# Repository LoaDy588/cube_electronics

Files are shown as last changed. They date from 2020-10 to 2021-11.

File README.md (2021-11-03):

# Cube Electronics

## Content

The repo currently contains KiCAD source files for the main board, interface board and a tiny sensor head.
It also includes all accompanying files, such as BOM.

## Building

The supplied `makefile` uses [KiKit](https://github.com/yaqwsx/KiKit) to automatically generate all output gerber files for JLCPCB.
Just run `make` in the top level directory to create all output gerbers and zip them in the `./gerber/` folder.

## 3D models, schematic symbols, footprints

This project relies on [LoaDy KiCAD Libs](https://github.com/LoaDy588/LoaDy_KiCAD_libs) for some footprints and the 3D models in the 3D preview on PCBNew

## License

The Main Board and Interface Board are licensed under CERN-OHL-W v2.

The MLX90393 sensor head is not licensed at all.

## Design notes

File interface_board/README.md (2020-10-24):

# Interface Board

This board serves as a sensor interface on the moving head.

It includes power regulators, GPIO and two communication busses - I2C and SPI.

It communicates with the main board via buffered 12V I2C bus.

## License

Copyright Oldřich Pecák 2020.

This source describes Open Hardware and is licensed under the CERN-OHL-W v2.

You may redistribute and modify this source and make products using it under the terms of the CERN-OHL-W v2 (https://ohwr.org/cern_ohl_w_v2.txt).

This source is distributed WITHOUT ANY EXPRESS OR IMPLIED WARRANTY, INCLUDING OF MERCHANTABILITY, SATISFACTORY QUALITY AND FITNESS FOR A PARTICULAR PURPOSE. Please see the CERN-OHL-W v2 for applicable conditions.

Source location: LICENSE.txt

As per CERN-OHL-W v2 section 4, should You produce hardware based on this source, You must where practicable maintain the Source Location visible on the external case of the Gizmo or other products you make using this source.

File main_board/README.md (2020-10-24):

# Main Board

This is the main control board for Cube.

## Features
- powered by STM32G4 170MHz Cortex-M4 MCU
- four independent TMC2209 stepper drivers
- fully protected 10x limit switch inputs capable of 12V input
- USB communication with PC
- I2C and UART passthrough to MCU
- 3V3, 5V and 12V(supply) power rails

## License

Copyright Oldřich Pecák 2020.

This source describes Open Hardware and is licensed under the CERN-OHL-W v2.

You may redistribute and modify this source and make products using it under the terms of the CERN-OHL-S v2 (https://ohwr.org/cern_ohl_w_v2.txt).

This source is distributed WITHOUT ANY EXPRESS OR IMPLIED WARRANTY, INCLUDING OF MERCHANTABILITY, SATISFACTORY QUALITY AND FITNESS FOR A PARTICULAR PURPOSE. Please see the CERN-OHL-W v2 for applicable conditions.

Source location: LICENSE.txt

As per CERN-OHL-W v2 section 4, should You produce hardware based on this source, You must where practicable maintain the Source Location visible on the external case of the Gizmo or other products you make using this source.

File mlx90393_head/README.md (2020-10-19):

# MLX90393

This is a tiny carrier board for the MLX90393 sensor.

## BOM

- Melexis MLX90393 sensor, in QFN-16 package
- 2x: 100nF X7R MLCC capacitor, 0603 package (imperial)

## License

No license, as this is extremely simple board.

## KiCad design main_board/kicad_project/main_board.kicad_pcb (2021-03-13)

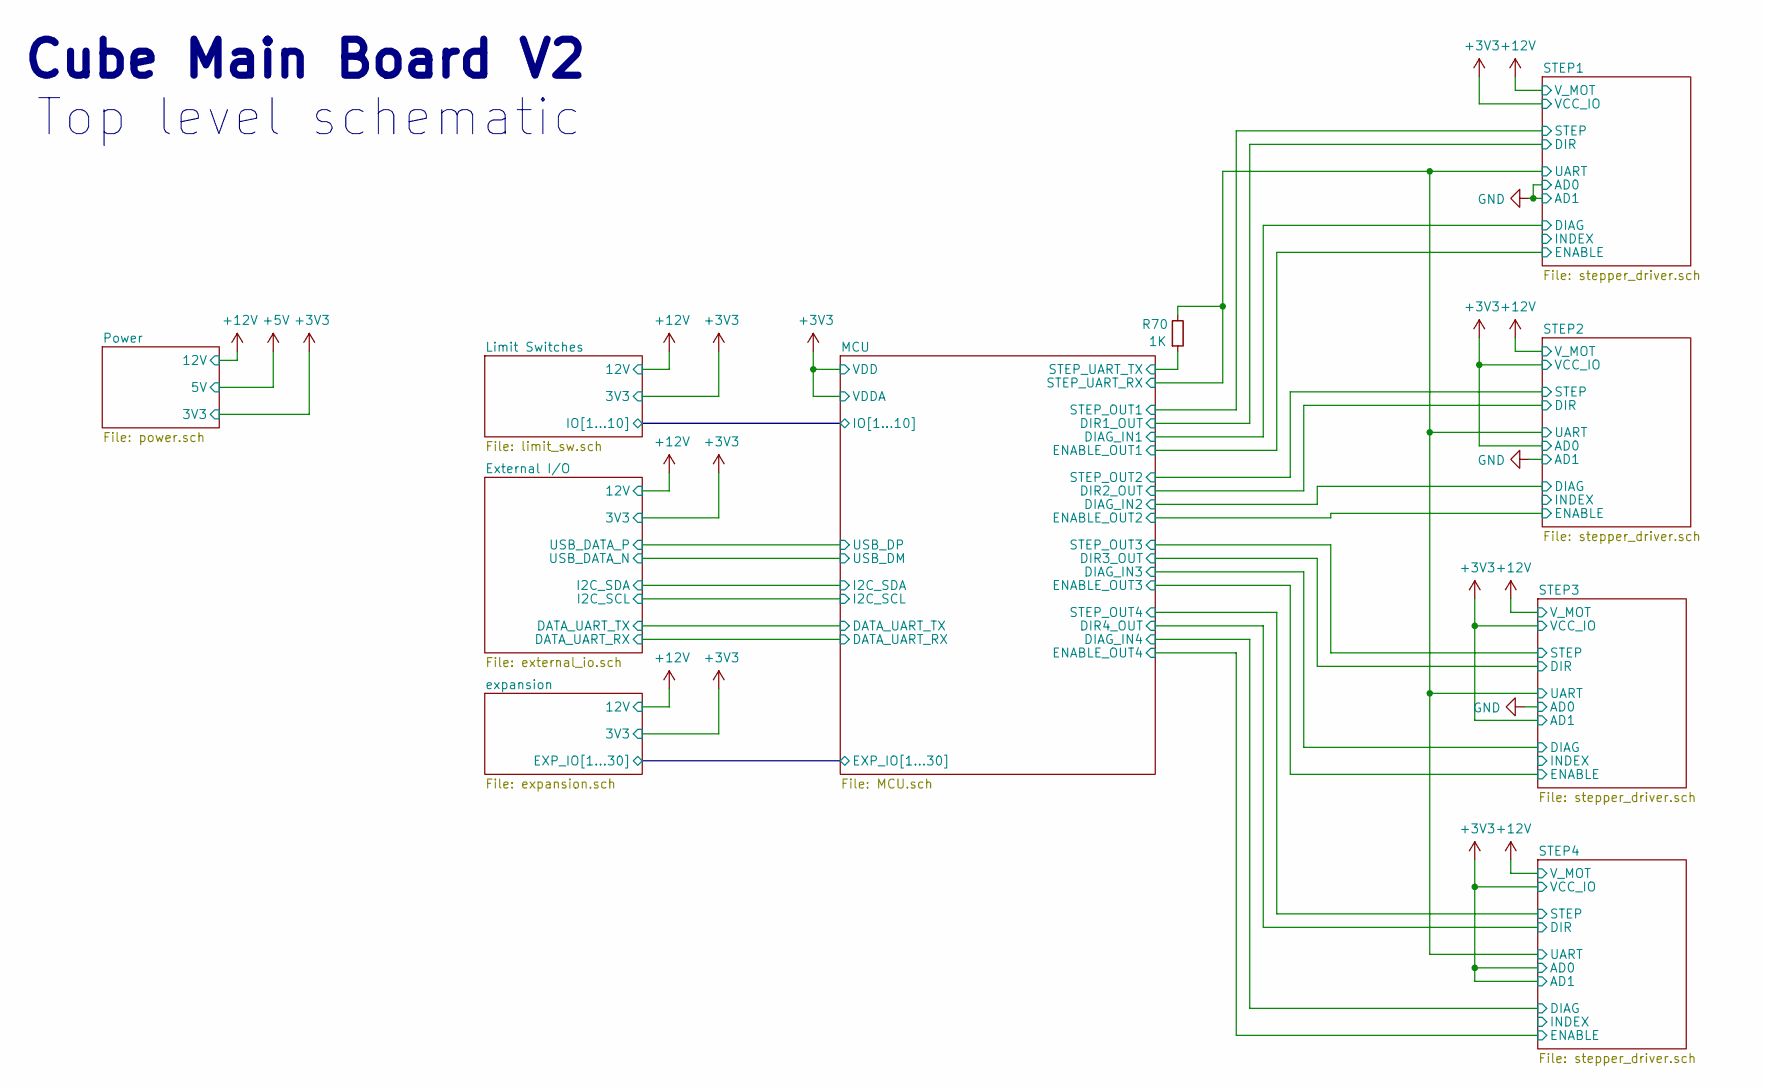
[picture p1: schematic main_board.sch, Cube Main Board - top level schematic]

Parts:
R70: 1K; R_0603_1608Metric

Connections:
/MCU/STEP_UART_RX: R70.2; also elsewhere on the board
/MCU/STEP_UART_TX: R70.1; also elsewhere on the board

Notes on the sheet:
Cube Main Board V2
Top level schematic

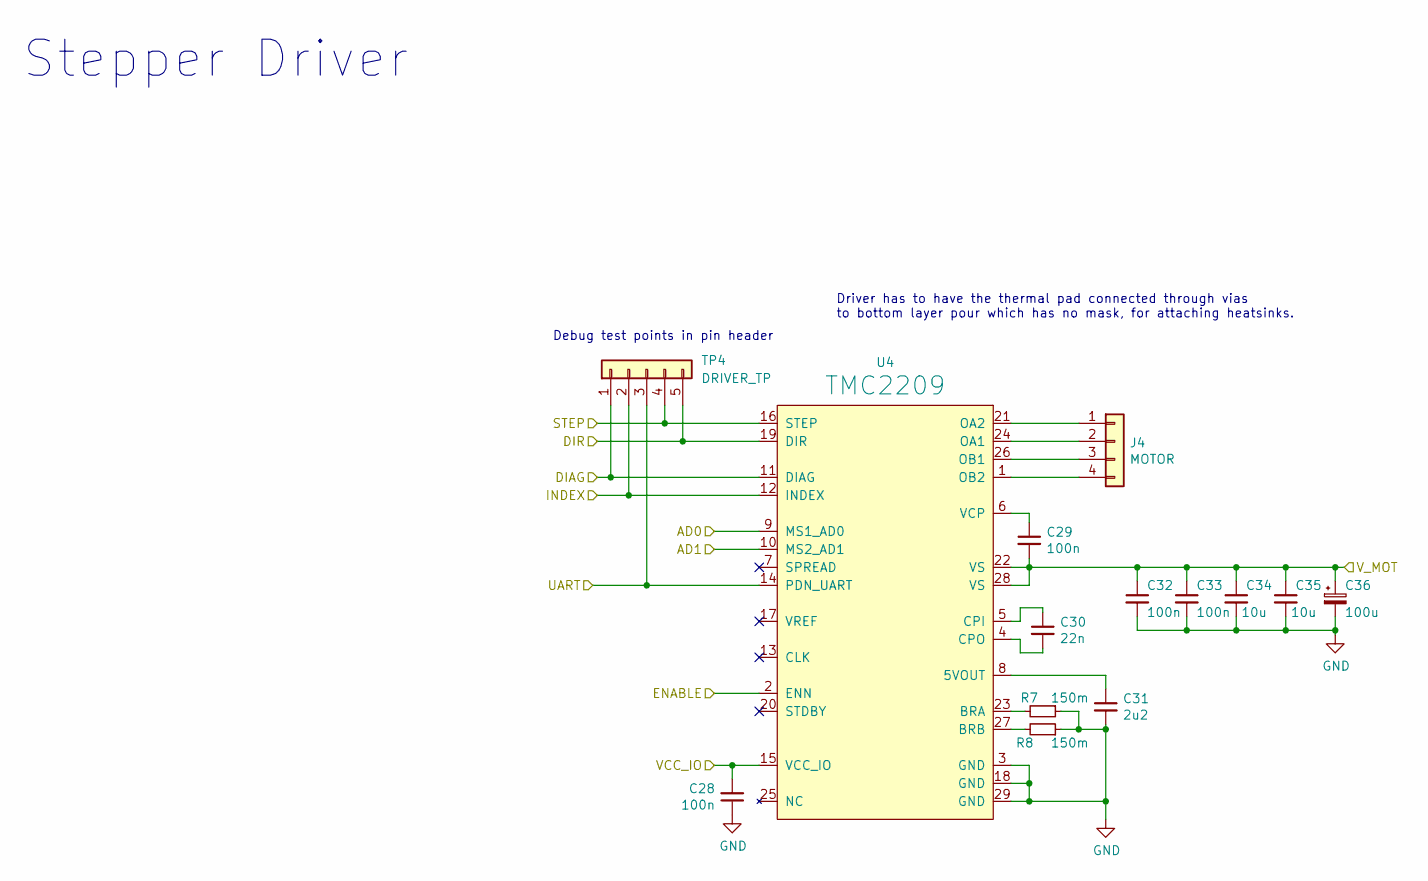
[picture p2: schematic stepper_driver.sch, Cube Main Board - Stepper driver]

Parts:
C1, C2, C5, C6: 100n; C_0603_1608Metric
C3: 22n; C_0603_1608Metric
C4: 2u2; C_0603_1608Metric
C7, C8: 10u; C_1210_3225Metric
C9: 100u; CP_Elec_8x10
J1: MOTOR; Molex_70543-0003
R1, R2: 150m; R_1206_3216Metric
TP1: DRIVER_TP; PinHeader_1x05_P2.54mm_Vertical
U1: TMC2209; TMC2209-LA

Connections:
+3V3: C1.2, U1.15 (VCC_IO); also elsewhere on the board
+12V: C2.2, C5.1, C6.1, C7.1, C8.1, C9.1, U1.22 (VS), U1.28 (VS); also elsewhere on the board
/MCU/STEP_UART_RX: TP1.3, U1.14 (PDN_UART); also elsewhere on the board
/STEP1/DIAG: TP1.1, U1.11 (DIAG); also elsewhere on the board
/STEP1/DIR: TP1.5, U1.19 (DIR); also elsewhere on the board
/STEP1/ENABLE: U1.2 (ENN); also elsewhere on the board
/STEP1/INDEX: TP1.2, U1.12 (INDEX)
/STEP1/STEP: TP1.4, U1.16 (STEP); also elsewhere on the board
GND: C1.1, C4.2, C5.2, C6.2, C7.2, C8.2, C9.2, R1.1, R2.1, U1.3 (GND), U1.9 (MS1_AD0), U1.10 (MS2_AD1), U1.18 (GND), U1.29 (GND); also elsewhere on the board
unnamed: C2.1, U1.6 (VCP)
unnamed: C3.1, U1.5 (CPI)
unnamed: C3.2, U1.4 (CPO)
unnamed: C4.1, U1.8 (5VOUT)
unnamed: J1.1, U1.21 (OA2)
unnamed: J1.2, U1.24 (OA1)
unnamed: J1.3, U1.26 (OB1)
unnamed: J1.4, U1.1 (OB2)
unnamed: R1.2, U1.23 (BRA)
unnamed: R2.2, U1.27 (BRB)

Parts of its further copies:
C10, C11, C14, C15, C19, C20, C23, C24, C28, C29, C32, C33: 100n; C_0603_1608Metric
C12, C21, C30: 22n; C_0603_1608Metric
C13, C22, C31: 2u2; C_0603_1608Metric
C16, C17, C25, C26, C34, C35: 10u; C_1210_3225Metric
C18, C27, C36: 100u; CP_Elec_8x10
J2, J3, J4: MOTOR; Molex_70543-0003
R3, R4, R5, R6, R7, R8: 150m; R_1206_3216Metric
TP2, TP3, TP4: DRIVER_TP; PinHeader_1x05_P2.54mm_Vertical
U2, U3, U4: TMC2209; TMC2209-LA

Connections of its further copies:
+3V3: C10.2, C19.2, C28.2, U2.9 (MS1_AD0), U2.15 (VCC_IO), U3.10 (MS2_AD1), U3.15 (VCC_IO), U4.9 (MS1_AD0), U4.10 (MS2_AD1), U4.15 (VCC_IO); also elsewhere on the board
+12V: C11.2, C14.1, C15.1, C16.1, C17.1, C18.1, C20.2, C23.1, C24.1, C25.1, C26.1, C27.1, C29.2, C32.1, C33.1, C34.1, C35.1, C36.1, U2.22 (VS), U2.28 (VS), U3.22 (VS), U3.28 (VS), U4.22 (VS), U4.28 (VS); also elsewhere on the board
/MCU/STEP_UART_RX: TP2.3, TP3.3, TP4.3, U2.14 (PDN_UART), U3.14 (PDN_UART), U4.14 (PDN_UART); also elsewhere on the board
/STEP2/DIAG: TP2.1, U2.11 (DIAG); also elsewhere on the board
/STEP2/DIR: TP2.5, U2.19 (DIR); also elsewhere on the board
/STEP2/ENABLE: U2.2 (ENN); also elsewhere on the board
/STEP2/INDEX: TP2.2, U2.12 (INDEX)
/STEP2/STEP: TP2.4, U2.16 (STEP); also elsewhere on the board
/STEP3/DIAG: TP3.1, U3.11 (DIAG); also elsewhere on the board
/STEP3/DIR: TP3.5, U3.19 (DIR); also elsewhere on the board
/STEP3/ENABLE: U3.2 (ENN); also elsewhere on the board
/STEP3/INDEX: TP3.2, U3.12 (INDEX)
/STEP3/STEP: TP3.4, U3.16 (STEP); also elsewhere on the board
/STEP4/DIAG: TP4.1, U4.11 (DIAG); also elsewhere on the board
/STEP4/DIR: TP4.5, U4.19 (DIR); also elsewhere on the board
/STEP4/ENABLE: U4.2 (ENN); also elsewhere on the board
/STEP4/INDEX: TP4.2, U4.12 (INDEX)
/STEP4/STEP: TP4.4, U4.16 (STEP); also elsewhere on the board
GND: C10.1, C13.2, C14.2, C15.2, C16.2, C17.2, C18.2, C19.1, C22.2, C23.2, C24.2, C25.2, C26.2, C27.2, C28.1, C31.2, C32.2, C33.2, C34.2, C35.2, C36.2, R3.1, R4.1, R5.1, R6.1, R7.1, R8.1, U2.3 (GND), U2.10 (MS2_AD1), U2.18 (GND), U2.29 (GND), U3.3 (GND), U3.9 (MS1_AD0), U3.18 (GND), U3.29 (GND), U4.3 (GND), U4.18 (GND), U4.29 (GND); also elsewhere on the board
unnamed: C11.1, U2.6 (VCP)
unnamed: C12.1, U2.5 (CPI)
unnamed: C12.2, U2.4 (CPO)
unnamed: C13.1, U2.8 (5VOUT)
unnamed: C20.1, U3.6 (VCP)
unnamed: C21.1, U3.5 (CPI)
unnamed: C21.2, U3.4 (CPO)
unnamed: C22.1, U3.8 (5VOUT)
unnamed: C29.1, U4.6 (VCP)
unnamed: C30.1, U4.5 (CPI)
unnamed: C30.2, U4.4 (CPO)
unnamed: C31.1, U4.8 (5VOUT)
unnamed: J2.1, U2.21 (OA2)
unnamed: J2.2, U2.24 (OA1)
unnamed: J2.3, U2.26 (OB1)
unnamed: J2.4, U2.1 (OB2)
unnamed: J3.1, U3.21 (OA2)
unnamed: J3.2, U3.24 (OA1)
unnamed: J3.3, U3.26 (OB1)
unnamed: J3.4, U3.1 (OB2)
unnamed: J4.1, U4.21 (OA2)
unnamed: J4.2, U4.24 (OA1)
unnamed: J4.3, U4.26 (OB1)
unnamed: J4.4, U4.1 (OB2)
unnamed: R3.2, U2.23 (BRA)
unnamed: R4.2, U2.27 (BRB)
unnamed: R5.2, U3.23 (BRA)
unnamed: R6.2, U3.27 (BRB)
unnamed: R7.2, U4.23 (BRA)
unnamed: R8.2, U4.27 (BRB)

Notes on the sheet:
Stepper Driver
Debug test points in pin header
Driver has to have the thermal pad connected through vias to bottom layer pour which has no mask, for attaching heatsinks.

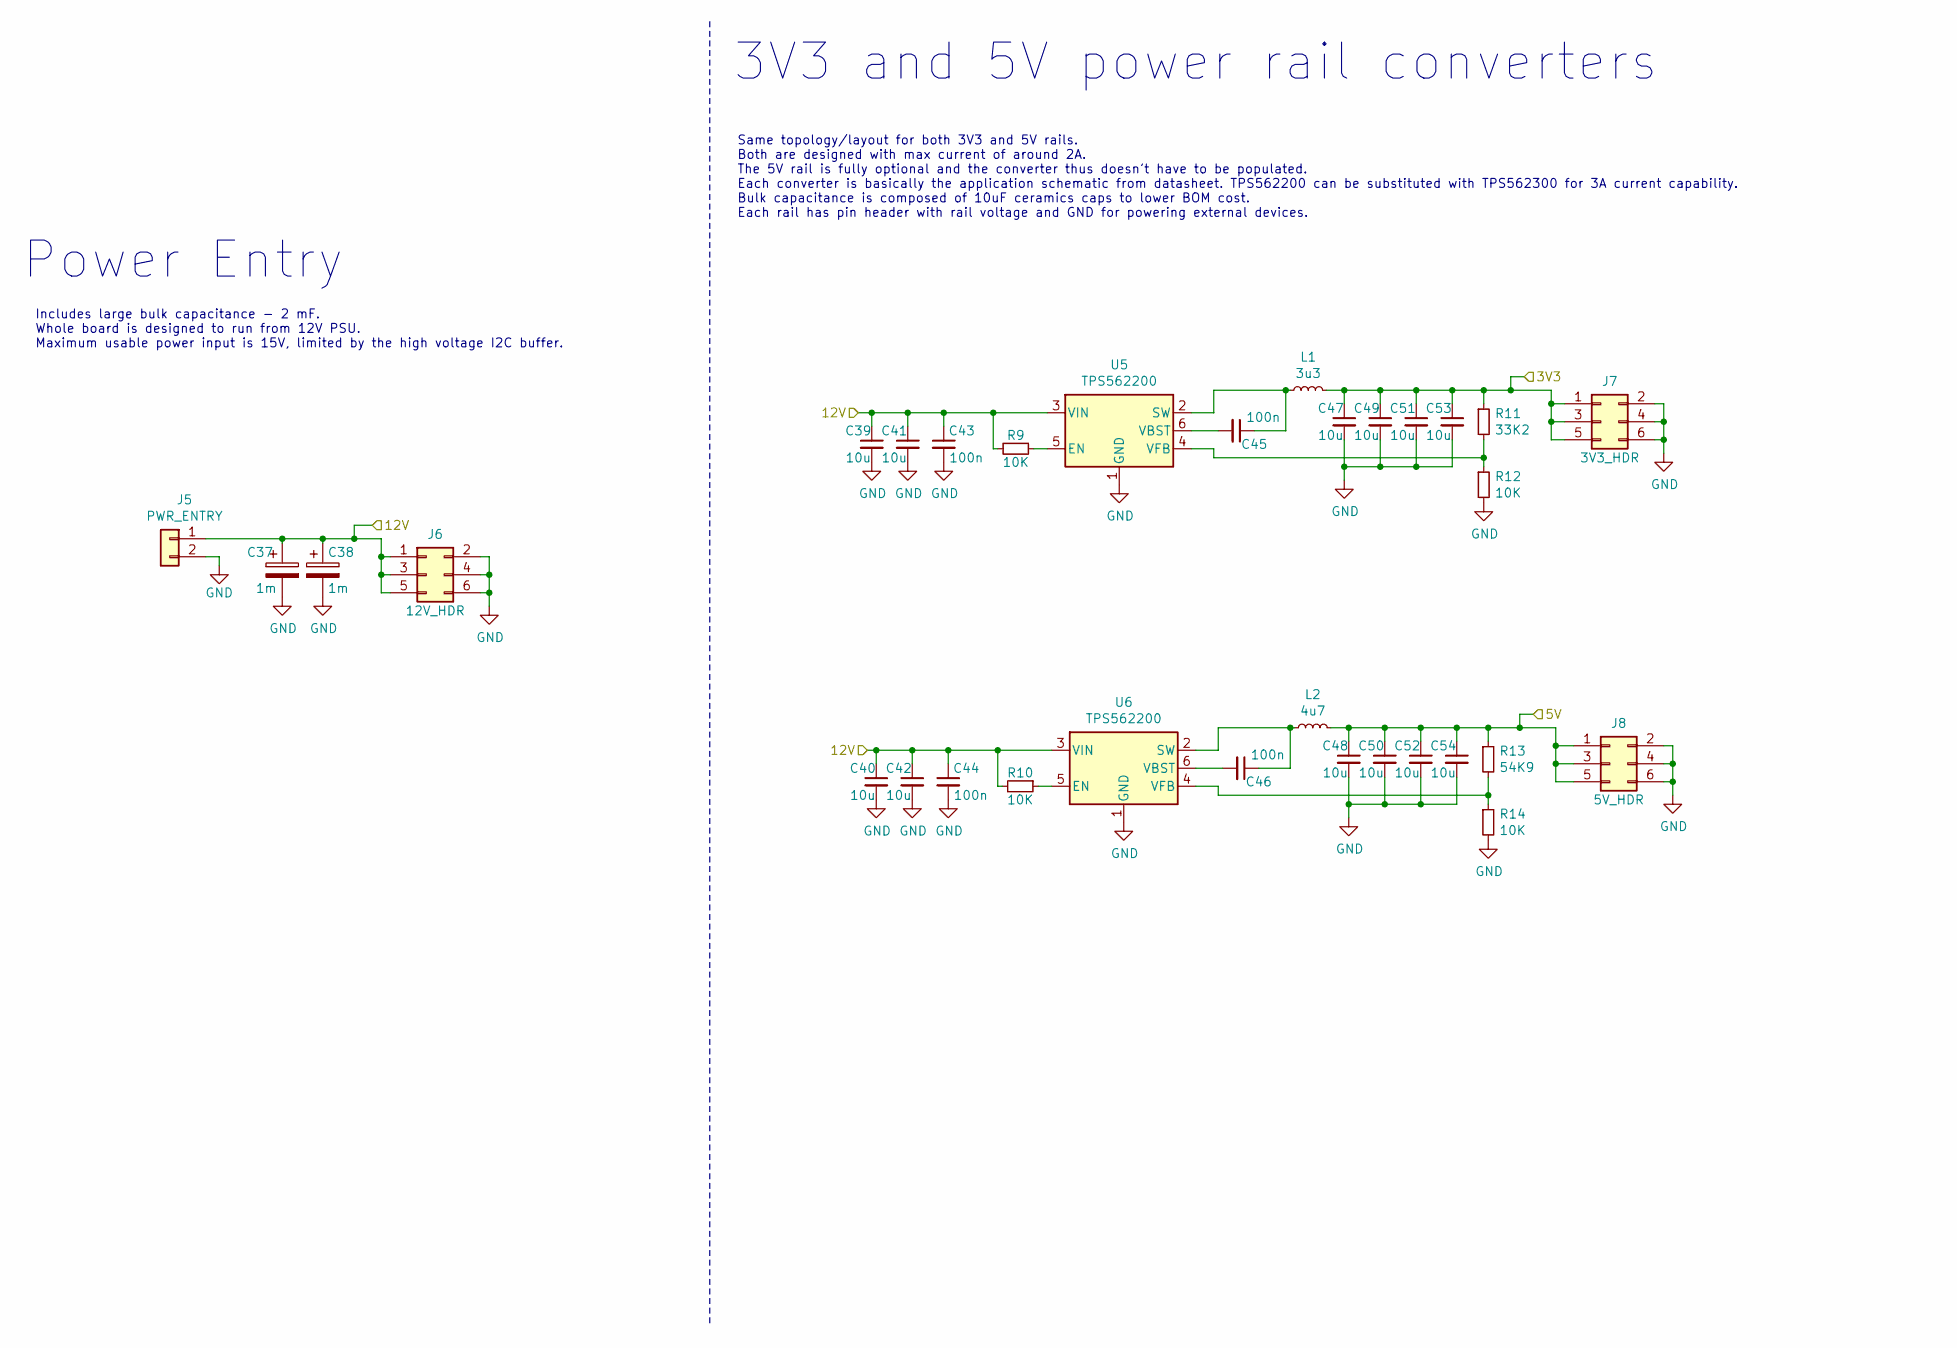
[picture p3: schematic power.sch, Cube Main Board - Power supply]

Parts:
C37, C38: 1m; CP_Radial_D12.5mm_P5.00mm
C39, C40, C41, C42, C47, C48, C49, C50, C51, C52, C53, C54: 10u; C_1210_3225Metric
C43, C44, C45, C46: 100n; C_0603_1608Metric
J5: PWR_ENTRY; PhoenixContact_MSTBA_2,5_2-G-5,08_1x02_P5.08mm_Horizontal
J6: 12V_HDR; PinHeader_2x03_P2.54mm_Vertical
J7: 3V3_HDR; PinHeader_2x03_P2.54mm_Vertical
J8: 5V_HDR; PinHeader_2x03_P2.54mm_Vertical
L1: 3u3; BOURNS_SRP3020TA
L2: 4u7; BOURNS_SRP3020TA
R9, R10, R12, R14: 10K; R_0603_1608Metric
R11: 33K2; R_0603_1608Metric
R13: 54K9; R_0603_1608Metric
U5, U6: TPS562200; SOT-23-6

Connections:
+3V3: C47.1, C49.1, C51.1, C53.1, J7.1, J7.3, J7.5, L1.2, R11.1; also elsewhere on the board
+5V: C48.1, C50.1, C52.1, C54.1, J8.1, J8.3, J8.5, L2.2, R13.1
+12V: C37.1, C38.1, C39.1, C40.1, C41.1, C42.1, C43.1, C44.1, J5.1, J6.1, J6.3, J6.5, R9.2, R10.2, U5.3 (VIN), U6.3 (VIN); also elsewhere on the board
GND: C37.2, C38.2, C39.2, C40.2, C41.2, C42.2, C43.2, C44.2, C47.2, C48.2, C49.2, C50.2, C51.2, C52.2, C53.2, C54.2, J5.2, J6.2, J6.4, J6.6, J7.2, J7.4, J7.6, J8.2, J8.4, J8.6, R12.2, R14.2, U5.1 (GND), U6.1 (GND); also elsewhere on the board
unnamed: C45.1, L1.1, U5.2 (SW)
unnamed: C45.2, U5.6 (VBST)
unnamed: C46.1, L2.1, U6.2 (SW)
unnamed: C46.2, U6.6 (VBST)
unnamed: R9.1, U5.5 (EN)
unnamed: R10.1, U6.5 (EN)
unnamed: R11.2, R12.1, U5.4 (VFB)
unnamed: R13.2, R14.1, U6.4 (VFB)

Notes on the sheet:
Power Entry
3V3 and 5V power rail converters
Includes large bulk capacitance - 2 mF. Whole board is designed to run from 12V PSU. Maximum usable power input is 15V, limited by the high voltage I2C buffer.
Same topology/layout for both 3V3 and 5V rails. Both are designed with max current of around 2A. The 5V rail is fully optional and the converter thus doesn't have to be populated. Each converter is basically the application schematic from datasheet. TPS562200 can be substituted with TPS562300 for 3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

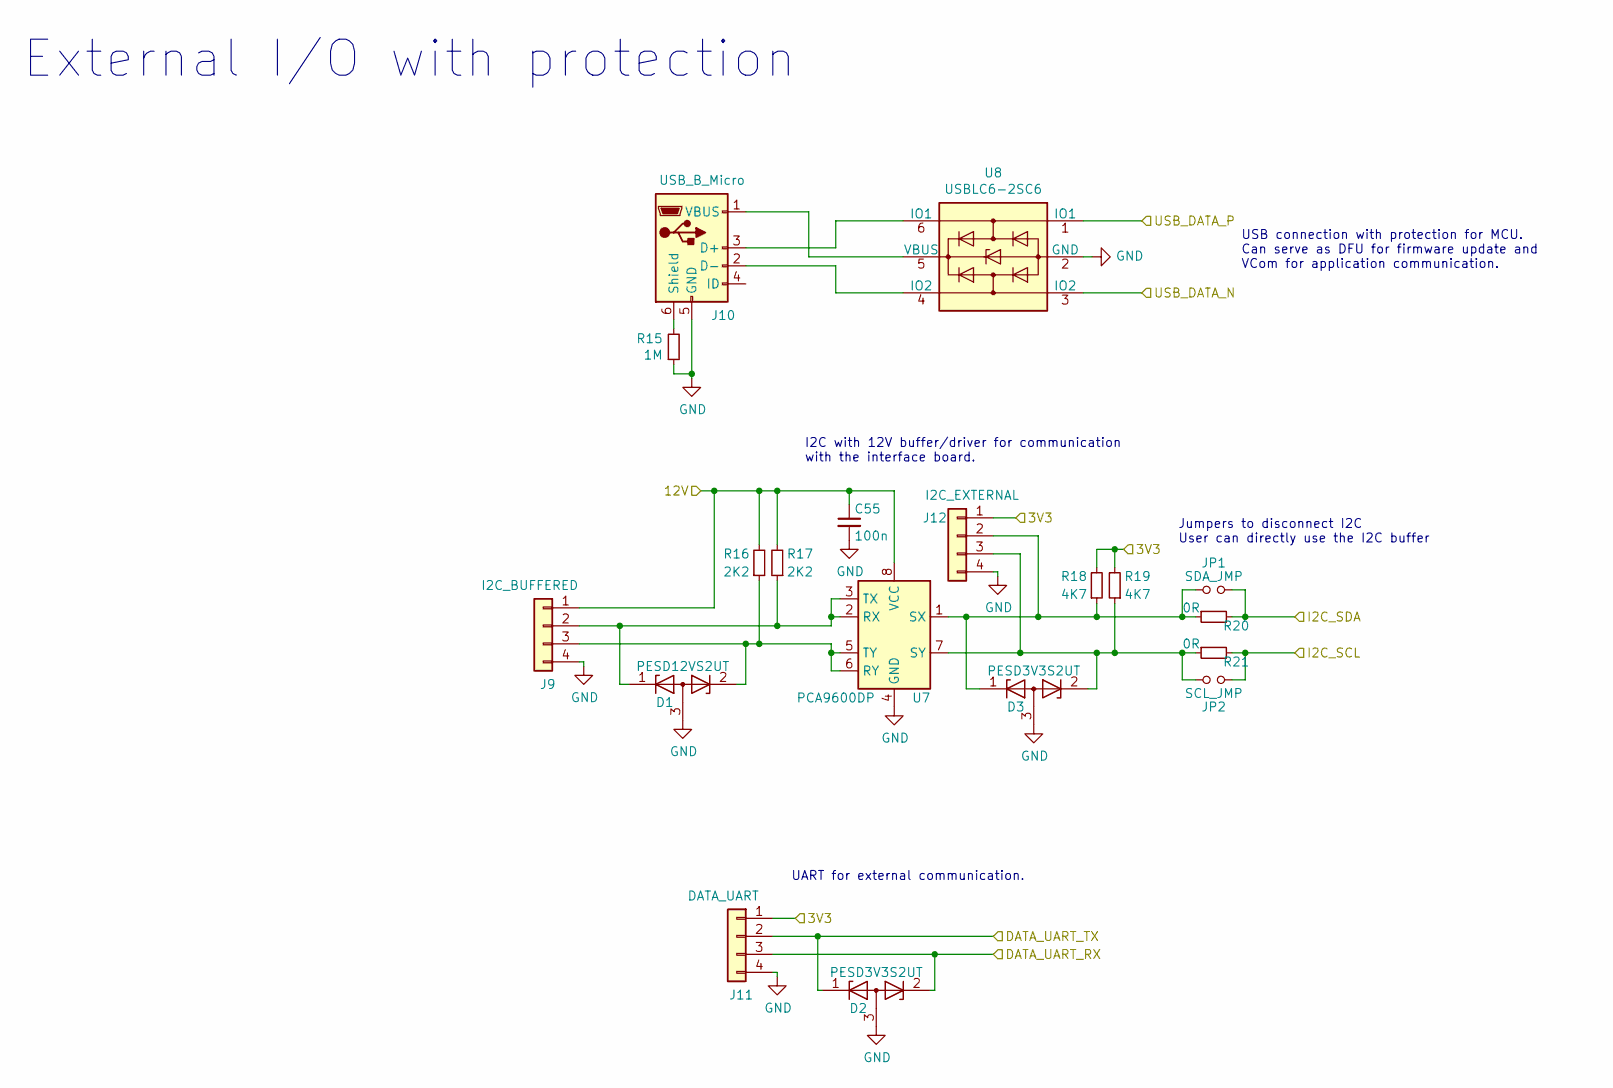
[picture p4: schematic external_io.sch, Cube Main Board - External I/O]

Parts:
C55: 100n; C_0603_1608Metric
D1: PESD12VS2UT; SOT-23
D2, D3: PESD3V3S2UT; SOT-23
J9: I2C_BUFFERED; Molex_70543-0003
J10: USB_B_Micro; USB_Micro-B_Molex_47346-0001
J11: DATA_UART; Molex_70543-0003
J12: I2C_EXTERNAL; Molex_70543-0003
JP1: SDA_JMP; PinHeader_1x02_P2.54mm_Vertical
JP2: SCL_JMP; PinHeader_1x02_P2.54mm_Vertical
R15: 1M; R_0603_1608Metric
R16, R17: 2K2; R_0603_1608Metric
R18, R19: 4K7; R_0603_1608Metric
R20, R21: 0R; R_0603_1608Metric
U7: PCA9600DP; TSSOP-8_3x3mm_P0.65mm
U8: USBLC6-2SC6; SOT-23-6

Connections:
+3V3: J11.1, J12.1, R18.2, R19.2; also elsewhere on the board
+12V: C55.1, J9.1, R16.2, R17.2, U7.8 (VCC); also elsewhere on the board
/External I/O/DATA_UART_RX: D2.2 (K), J11.3; also elsewhere on the board
/External I/O/DATA_UART_TX: D2.1 (K), J11.2; also elsewhere on the board
/External I/O/I2C_SCL: JP2.1, R21.2; also elsewhere on the board
/External I/O/I2C_SDA: JP1.2, R20.2; also elsewhere on the board
/External I/O/USB_DATA_N: U8.3 (IO2); also elsewhere on the board
/External I/O/USB_DATA_P: U8.1 (IO1); also elsewhere on the board
GND: C55.2, D1.3 (A), D2.3 (A), D3.3 (A), J9.4, J10.5 (GND), J11.4, J12.4, R15.1, U7.4 (GND), U8.2 (GND); also elsewhere on the board
unnamed: D1.1 (K), J9.2, R17.1, U7.2 (RX), U7.3 (TX)
unnamed: D1.2 (K), J9.3, R16.1, U7.5 (TY), U7.6 (RY)
unnamed: D3.1 (K), J12.2, JP1.1, R18.1, R20.1, U7.1 (SX)
unnamed: D3.2 (K), J12.3, JP2.2, R19.1, R21.1, U7.7 (SY)
unnamed: J10.1 (VBUS), U8.5 (VBUS)
unnamed: J10.2 (D-), U8.4 (IO2)
unnamed: J10.3 (D+), U8.6 (IO1)
unnamed: J10.6 (Shield), R15.2

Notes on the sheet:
External I/O with protection
Jumpers to disconnect I2C User can directly use the I2C buffer
USB connection with protection for MCU. Can serve as DFU for firmware update and VCom for application communication.
I2C with 12V buffer/driver for communication with the interface board.
UART for external communication.

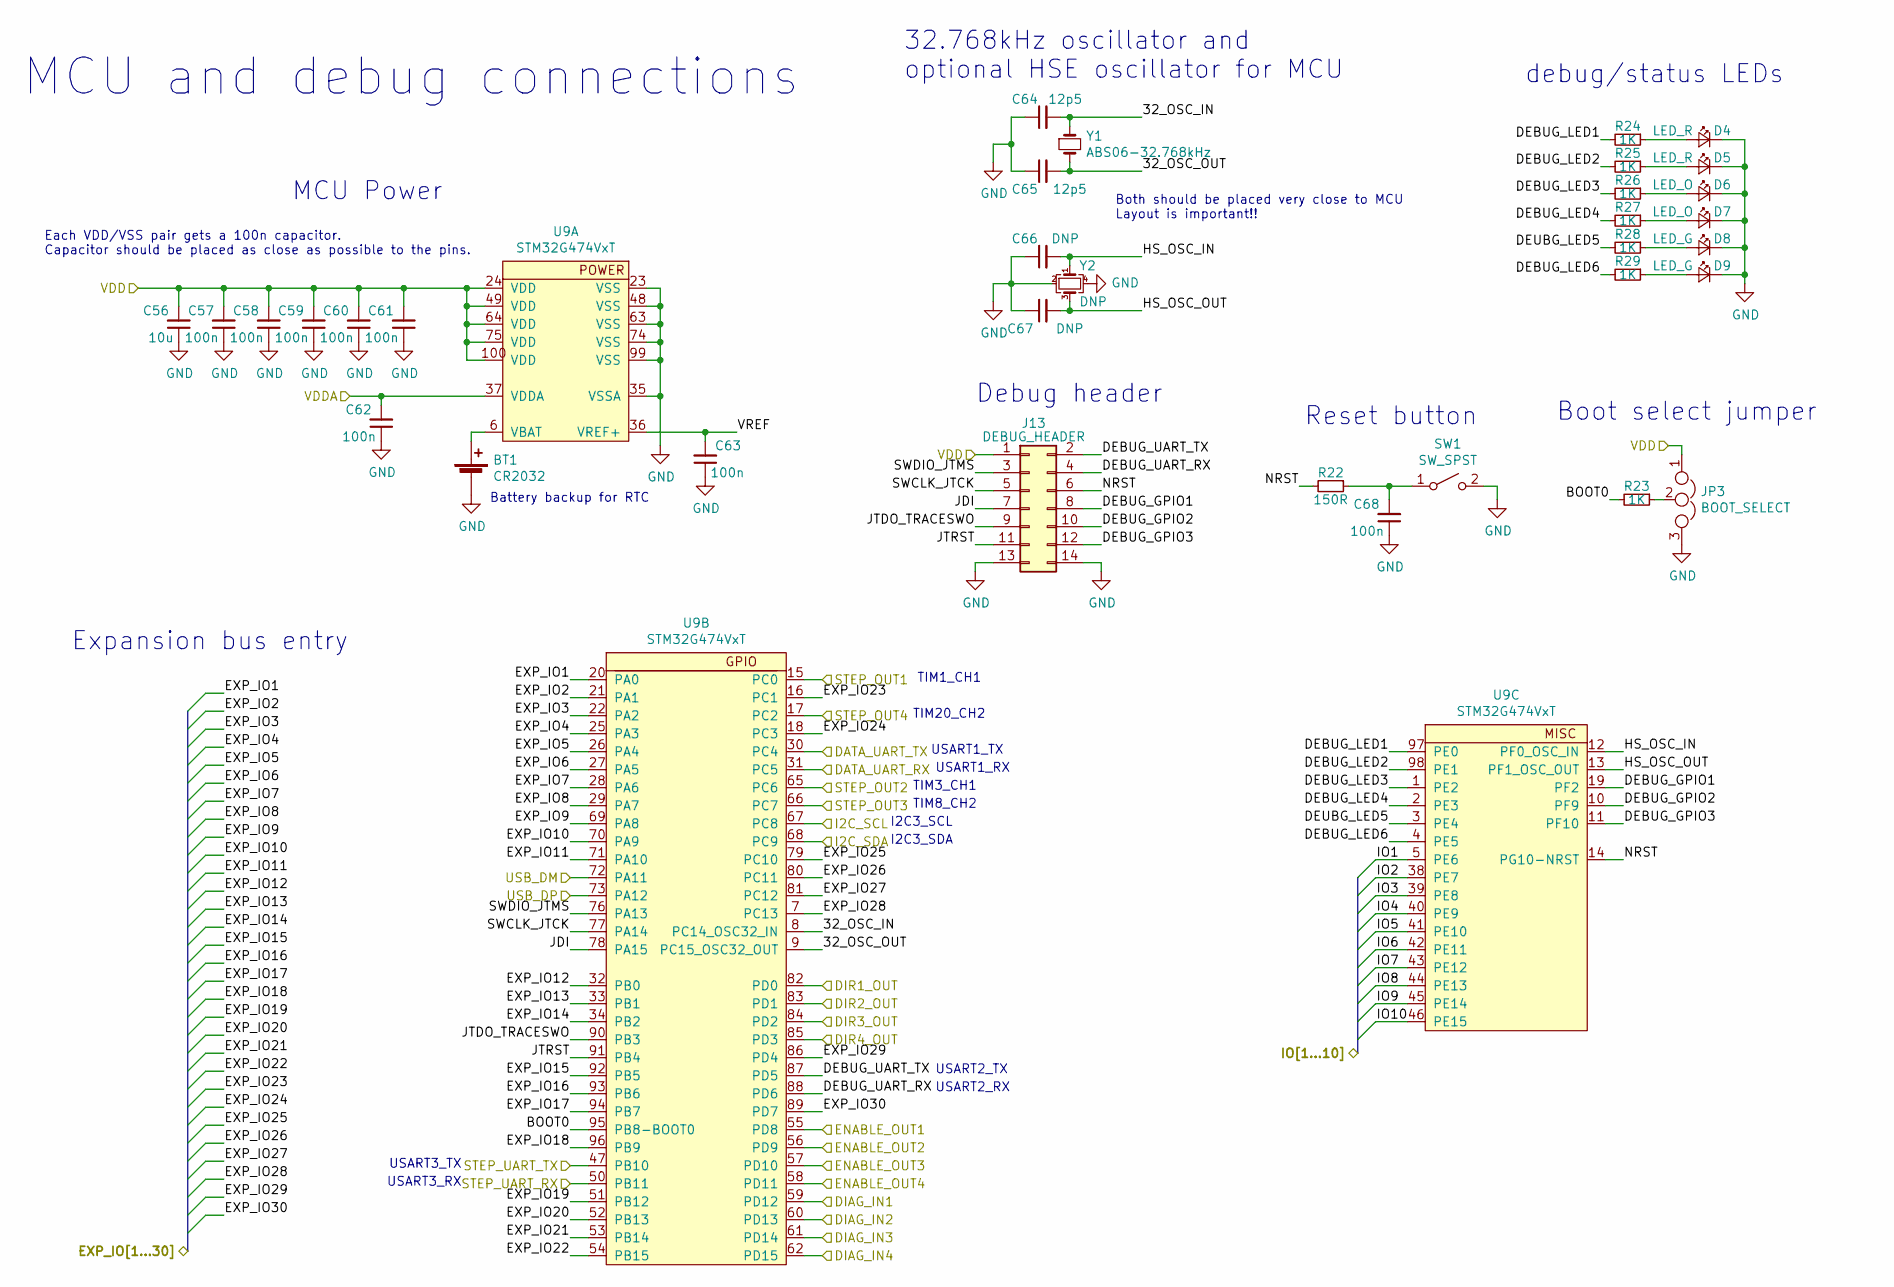
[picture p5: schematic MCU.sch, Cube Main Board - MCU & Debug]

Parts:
BT1: CR2032; CR2032_SMD
C56: 10u; C_1210_3225Metric
C57, C58, C59, C60, C61, C62, C63, C68: 100n; C_0603_1608Metric
C64, C65: 12p5; C_0603_1608Metric
C66, C67: DNP; C_0603_1608Metric
D4, D5: LED_R; D_0603_1608Metric
D6, D7: LED_O; D_0603_1608Metric
D8, D9: LED_G; D_0603_1608Metric
J13: DEBUG_HEADER; PinHeader_2x07_P2.54mm_Vertical
JP3: BOOT_SELECT; PinHeader_1x03_P2.54mm_Vertical
R22: 150R; R_0603_1608Metric
R23, R24, R25, R26, R27, R28, R29: 1K; R_0603_1608Metric
SW1: SW_SPST; SW_PUSH_6mm_H5mm
U9: STM32G474VxT; LQFP-100_14x14mm_P0.5mm
Y1: ABS06-32.768kHz; Crystal_SMD_2012-2Pin_2.0x1.2mm
Y2: DNP; Crystal_SMD_2016-4Pin_2.0x1.6mm

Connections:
+3V3: C56.2, C57.2, C58.2, C59.2, C60.2, C61.2, C62.2, J13.1, JP3.1, U9.24 (VDD), U9.37 (VDDA), U9.49 (VDD), U9.64 (VDD), U9.75 (VDD), U9.100 (VDD); also elsewhere on the board
/External I/O/DATA_UART_RX: U9.31 (PC5); also elsewhere on the board
/External I/O/DATA_UART_TX: U9.30 (PC4); also elsewhere on the board
/External I/O/I2C_SCL: U9.67 (PC8); also elsewhere on the board
/External I/O/I2C_SDA: U9.68 (PC9); also elsewhere on the board
/External I/O/USB_DATA_N: U9.72 (PA11); also elsewhere on the board
/External I/O/USB_DATA_P: U9.73 (PA12); also elsewhere on the board
/Limit Switches/IO1: U9.5 (PE6); also elsewhere on the board
/Limit Switches/IO2: U9.38 (PE7); also elsewhere on the board
/Limit Switches/IO3: U9.39 (PE8); also elsewhere on the board
/Limit Switches/IO4: U9.40 (PE9); also elsewhere on the board
/Limit Switches/IO5: U9.41 (PE10); also elsewhere on the board
/Limit Switches/IO6: U9.42 (PE11); also elsewhere on the board
/Limit Switches/IO7: U9.43 (PE12); also elsewhere on the board
/Limit Switches/IO8: U9.44 (PE13); also elsewhere on the board
/Limit Switches/IO9: U9.45 (PE14); also elsewhere on the board
/Limit Switches/IO10: U9.46 (PE15); also elsewhere on the board
/MCU/32_OSC_IN: C64.2, U9.8 (PC14_OSC32_IN), Y1.1
/MCU/32_OSC_OUT: C65.2, U9.9 (PC15_OSC32_OUT), Y1.2
/MCU/BOOT0: R23.2, U9.95 (PB8-BOOT0)
/MCU/DEBUG_GPIO1: J13.8, U9.19 (PF2)
/MCU/DEBUG_GPIO2: J13.10, U9.10 (PF9)
/MCU/DEBUG_GPIO3: J13.12, U9.11 (PF10)
/MCU/DEBUG_LED1: R24.2, U9.97 (PE0)
/MCU/DEBUG_LED2: R25.2, U9.98 (PE1)
/MCU/DEBUG_LED3: R26.2, U9.1 (PE2)
/MCU/DEBUG_LED4: R27.2, U9.2 (PE3)
/MCU/DEBUG_LED6: R29.2, U9.4 (PE5)
/MCU/DEBUG_UART_RX: J13.4, U9.88 (PD6)
/MCU/DEBUG_UART_TX: J13.2, U9.87 (PD5)
/MCU/DEUBG_LED5: R28.2, U9.3 (PE4)
/MCU/EXP_IO1: U9.20 (PA0); also elsewhere on the board
/MCU/EXP_IO2: U9.21 (PA1); also elsewhere on the board
/MCU/EXP_IO3: U9.22 (PA2); also elsewhere on the board
/MCU/EXP_IO4: U9.25 (PA3); also elsewhere on the board
/MCU/EXP_IO5: U9.26 (PA4); also elsewhere on the board
/MCU/EXP_IO6: U9.27 (PA5); also elsewhere on the board
/MCU/EXP_IO7: U9.28 (PA6); also elsewhere on the board
/MCU/EXP_IO8: U9.29 (PA7); also elsewhere on the board
/MCU/EXP_IO9: U9.69 (PA8); also elsewhere on the board
/MCU/EXP_IO10: U9.70 (PA9); also elsewhere on the board
/MCU/EXP_IO11: U9.71 (PA10); also elsewhere on the board
/MCU/EXP_IO12: U9.32 (PB0); also elsewhere on the board
/MCU/EXP_IO13: U9.33 (PB1); also elsewhere on the board
/MCU/EXP_IO14: U9.34 (PB2); also elsewhere on the board
/MCU/EXP_IO15: U9.92 (PB5); also elsewhere on the board
/MCU/EXP_IO16: U9.93 (PB6); also elsewhere on the board
/MCU/EXP_IO17: U9.94 (PB7); also elsewhere on the board
/MCU/EXP_IO18: U9.96 (PB9); also elsewhere on the board
/MCU/EXP_IO19: U9.51 (PB12); also elsewhere on the board
/MCU/EXP_IO20: U9.52 (PB13); also elsewhere on the board
/MCU/EXP_IO21: U9.53 (PB14); also elsewhere on the board
/MCU/EXP_IO22: U9.54 (PB15); also elsewhere on the board
/MCU/EXP_IO23: U9.16 (PC1); also elsewhere on the board
/MCU/EXP_IO24: U9.18 (PC3); also elsewhere on the board
/MCU/EXP_IO25: U9.79 (PC10); also elsewhere on the board
/MCU/EXP_IO26: U9.80 (PC11); also elsewhere on the board
/MCU/EXP_IO27: U9.81 (PC12); also elsewhere on the board
/MCU/EXP_IO28: U9.7 (PC13); also elsewhere on the board
/MCU/EXP_IO29: U9.86 (PD4); also elsewhere on the board
/MCU/EXP_IO30: U9.89 (PD7); also elsewhere on the board
/MCU/HS_OSC_IN: C66.2, U9.12 (PF0_OSC_IN), Y2.1
/MCU/HS_OSC_OUT: C67.2, U9.13 (PF1_OSC_OUT), Y2.3
/MCU/JDI: J13.7, U9.78 (PA15)
/MCU/JTDO_TRACESWO: J13.9, U9.90 (PB3)
/MCU/JTRST: J13.11, U9.91 (PB4)
/MCU/NRST: J13.6, R22.2, U9.14 (PG10-NRST)
/MCU/STEP_UART_RX: U9.50 (PB11); also elsewhere on the board
/MCU/STEP_UART_TX: U9.47 (PB10); also elsewhere on the board
/MCU/SWCLK_JTCK: J13.5, U9.77 (PA14)
/MCU/SWDIO_JTMS: J13.3, U9.76 (PA13)
/MCU/VREF: C63.2, U9.36 (VREF+)
/STEP1/DIAG: U9.59 (PD12); also elsewhere on the board
/STEP1/DIR: U9.82 (PD0); also elsewhere on the board
/STEP1/ENABLE: U9.55 (PD8); also elsewhere on the board
/STEP1/STEP: U9.15 (PC0); also elsewhere on the board
/STEP2/DIAG: U9.60 (PD13); also elsewhere on the board
/STEP2/DIR: U9.83 (PD1); also elsewhere on the board
/STEP2/ENABLE: U9.56 (PD9); also elsewhere on the board
/STEP2/STEP: U9.65 (PC6); also elsewhere on the board
/STEP3/DIAG: U9.61 (PD14); also elsewhere on the board
/STEP3/DIR: U9.84 (PD2); also elsewhere on the board
/STEP3/ENABLE: U9.57 (PD10); also elsewhere on the board
/STEP3/STEP: U9.66 (PC7); also elsewhere on the board
/STEP4/DIAG: U9.62 (PD15); also elsewhere on the board
/STEP4/DIR: U9.85 (PD3); also elsewhere on the board
/STEP4/ENABLE: U9.58 (PD11); also elsewhere on the board
/STEP4/STEP: U9.17 (PC2); also elsewhere on the board
GND: BT1.2 (-), C56.1, C57.1, C58.1, C59.1, C60.1, C61.1, C62.1, C63.1, C64.1, C65.1, C66.1, C67.1, C68.1, D4.1 (K), D5.1 (K), D6.1 (K), D7.1 (K), D8.1 (K), D9.1 (K), J13.13, J13.14, JP3.3, SW1.2 (B), U9.23 (VSS), U9.35 (VSSA), U9.48 (VSS), U9.63 (VSS), U9.74 (VSS), U9.99 (VSS), Y2.2, Y2.4; also elsewhere on the board
unnamed: BT1.1 (+), U9.6 (VBAT)
unnamed: C68.2, R22.1, SW1.1 (A)
unnamed: D4.2 (A), R24.1
unnamed: D5.2 (A), R25.1
unnamed: D6.2 (A), R26.1
unnamed: D7.2 (A), R27.1
unnamed: D8.2 (A), R28.1
unnamed: D9.2 (A), R29.1
unnamed: JP3.2, R23.1

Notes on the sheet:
TIM1_CH1
TIM3_CH1
TIM8_CH2
TIM20_CH2
USART3_TX
USART3_RX
USART1_TX
USART1_RX
USART2_TX
USART2_RX
I2C3_SCL
I2C3_SDA
MCU and debug connections
Boot select jumper
Reset button
32.768kHz oscillator and optional HSE oscillator for MCU
debug/status LEDs
Both should be placed very close to MCU Layout is important!!
Expansion bus entry
MCU Power
Each VDD/VSS pair gets a 100n capacitor. Capacitor should be placed as close as possible to the pins.
Debug header
Battery backup for RTC

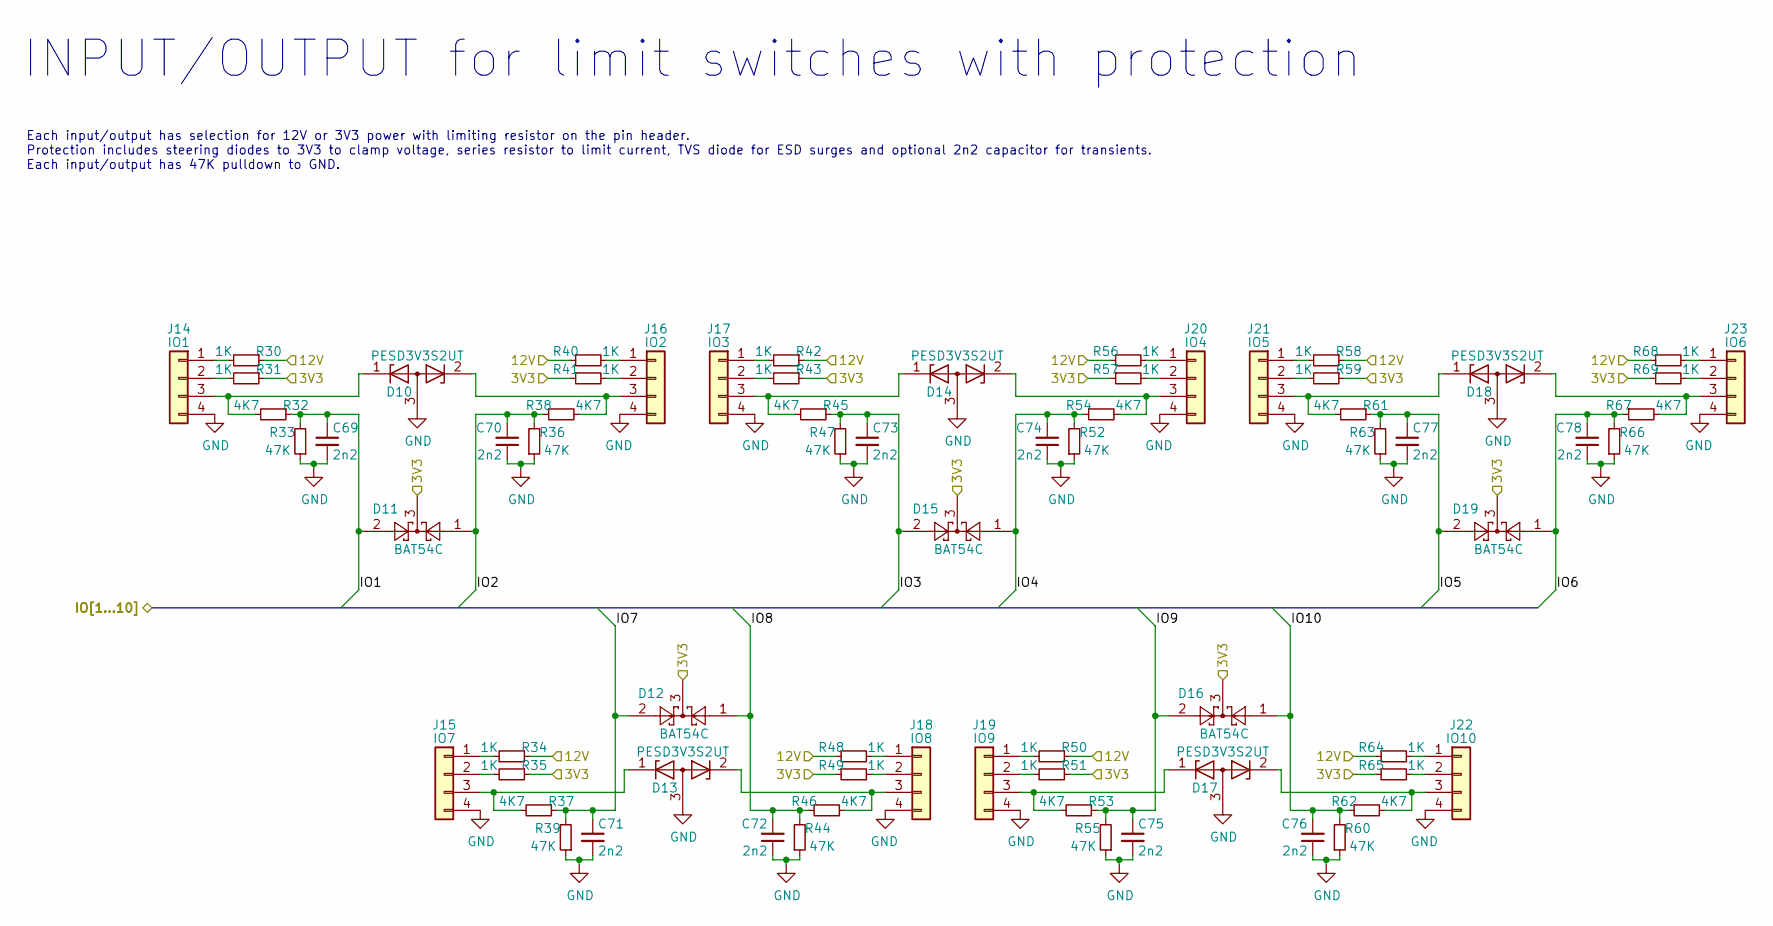
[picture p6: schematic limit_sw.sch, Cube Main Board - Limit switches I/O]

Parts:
C69, C70, C71, C72, C73, C74, C75, C76, C77, C78: 2n2; C_0603_1608Metric
D10, D13, D14, D17, D18: PESD3V3S2UT; SOT-23
D11, D12, D15, D16, D19: BAT54C; SOT-23
J14: IO1; Molex_70543-0003
J15: IO7; Molex_70543-0003
J16: IO2; Molex_70543-0003
J17: IO3; Molex_70543-0003
J18: IO8; Molex_70543-0003
J19: IO9; Molex_70543-0003
J20: IO4; Molex_70543-0003
J21: IO5; Molex_70543-0003
J22: IO10; Molex_70543-0003
J23: IO6; Molex_70543-0003
R30, R31, R34, R35, R40, R41, R42, R43, R48, R49, R50, R51, R56, R57, R58, R59, R64, R65, R68, R69: 1K; R_0603_1608Metric
R32, R37, R38, R45, R46, R53, R54, R61, R62, R67: 4K7; R_0603_1608Metric
R33, R36, R39, R44, R47, R52, R55, R60, R63, R66: 47K; R_0603_1608Metric

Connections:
+3V3: D11.3, D12.3, D15.3, D16.3, D19.3, R31.1, R35.1, R41.1, R43.1, R49.1, R51.1, R57.1, R59.1, R65.1, R69.1; also elsewhere on the board
+12V: R30.1, R34.1, R40.1, R42.1, R48.1, R50.1, R56.1, R58.1, R64.1, R68.1; also elsewhere on the board
/Limit Switches/IO1: C69.1, D11.2, R32.1, R33.2; also elsewhere on the board
/Limit Switches/IO2: C70.2, D11.1, R36.2, R38.1; also elsewhere on the board
/Limit Switches/IO3: C73.1, D15.2, R45.1, R47.2; also elsewhere on the board
/Limit Switches/IO4: C74.2, D15.1, R52.2, R54.1; also elsewhere on the board
/Limit Switches/IO5: C77.1, D19.2, R61.1, R63.2; also elsewhere on the board
/Limit Switches/IO6: C78.2, D19.1, R66.2, R67.1; also elsewhere on the board
/Limit Switches/IO7: C71.1, D12.2, R37.1, R39.2; also elsewhere on the board
/Limit Switches/IO8: C72.2, D12.1, R44.2, R46.1; also elsewhere on the board
/Limit Switches/IO9: C75.1, D16.2, R53.1, R55.2; also elsewhere on the board
/Limit Switches/IO10: C76.2, D16.1, R60.2, R62.1; also elsewhere on the board
GND: C69.2, C70.1, C71.2, C72.1, C73.2, C74.1, C75.2, C76.1, C77.2, C78.1, D10.3 (A), D13.3 (A), D14.3 (A), D17.3 (A), D18.3 (A), J14.4, J15.4, J16.4, J17.4, J18.4, J19.4, J20.4, J21.4, J22.4, J23.4, R33.1, R36.1, R39.1, R44.1, R47.1, R52.1, R55.1, R60.1, R63.1, R66.1; also elsewhere on the board
unnamed: D10.1 (K), J14.3, R32.2
unnamed: D10.2 (K), J16.3, R38.2
unnamed: D13.1 (K), J15.3, R37.2
unnamed: D13.2 (K), J18.3, R46.2
unnamed: D14.1 (K), J17.3, R45.2
unnamed: D14.2 (K), J20.3, R54.2
unnamed: D17.1 (K), J19.3, R53.2
unnamed: D17.2 (K), J22.3, R62.2
unnamed: D18.1 (K), J21.3, R61.2
unnamed: D18.2 (K), J23.3, R67.2
unnamed: J14.1, R30.2
unnamed: J14.2, R31.2
unnamed: J15.1, R34.2
unnamed: J15.2, R35.2
unnamed: J16.1, R40.2
unnamed: J16.2, R41.2
unnamed: J17.1, R42.2
unnamed: J17.2, R43.2
unnamed: J18.1, R48.2
unnamed: J18.2, R49.2
unnamed: J19.1, R50.2
unnamed: J19.2, R51.2
unnamed: J20.1, R56.2
unnamed: J20.2, R57.2
unnamed: J21.1, R58.2
unnamed: J21.2, R59.2
unnamed: J22.1, R64.2
unnamed: J22.2, R65.2
unnamed: J23.1, R68.2
unnamed: J23.2, R69.2

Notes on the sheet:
INPUT/OUTPUT for limit switches with protection
Each input/output has selection for 12V or 3V3 power with limiting resistor on the pin header. Protection includes steering diodes to 3V3 to clamp voltage, series resistor to limit current, TVS diode for ESD surges and optional 2n2 capacitor for transients. Each input/output has 47K pulldown to GND.

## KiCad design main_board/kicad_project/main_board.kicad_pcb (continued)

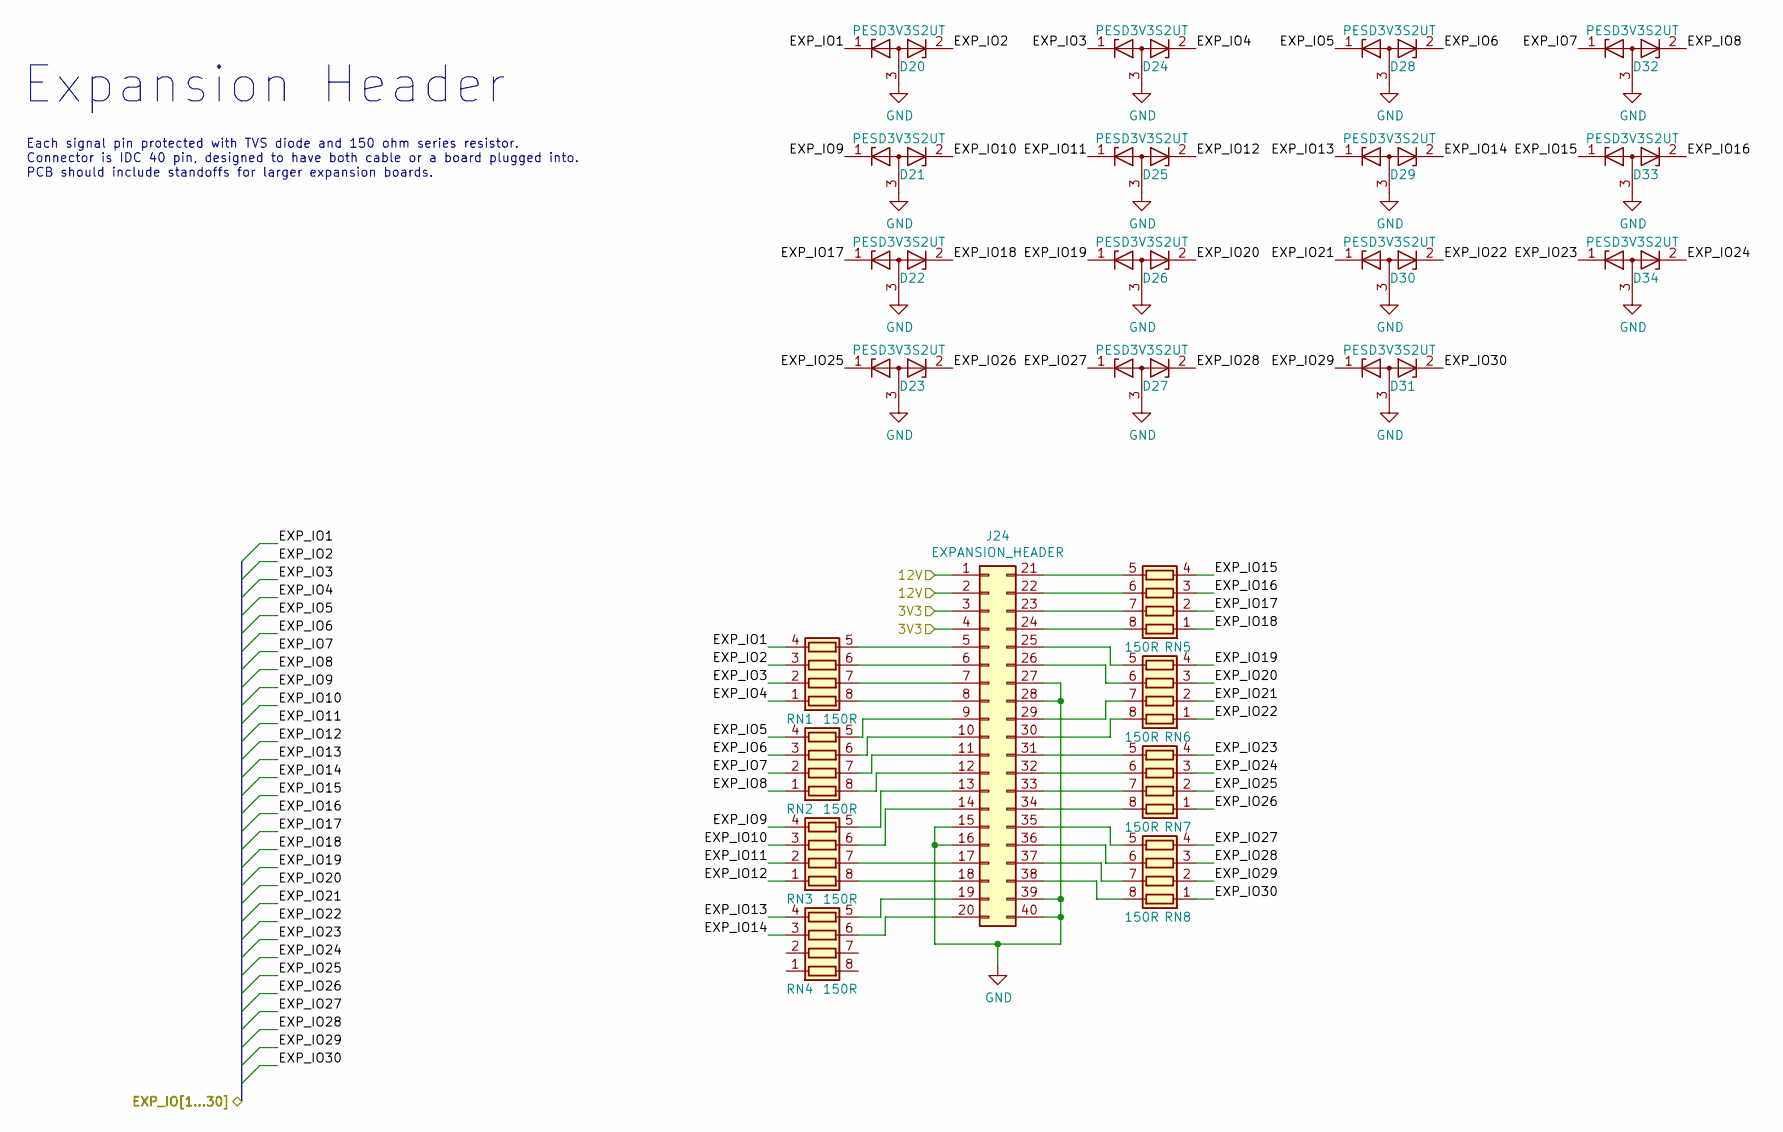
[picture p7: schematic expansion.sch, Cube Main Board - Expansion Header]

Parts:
D20, D21, D22, D23, D24, D25, D26, D27, D28, D29, D30, D31, D32, D33, D34: PESD3V3S2UT; SOT-23
J24: EXPANSION_HEADER; IDC-Header_2x20_P2.54mm_Vertical
RN1, RN2, RN3, RN4, RN5, RN6, RN7, RN8: 150R; R_Array_Convex_4x0603

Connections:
+3V3: J24.3, J24.4; also elsewhere on the board
+12V: J24.1, J24.2; also elsewhere on the board
/MCU/EXP_IO1: D20.1 (K), RN1.4 (R4.1); also elsewhere on the board
/MCU/EXP_IO2: D20.2 (K), RN1.3 (R3.1); also elsewhere on the board
/MCU/EXP_IO3: D24.1 (K), RN1.2 (R2.1); also elsewhere on the board
/MCU/EXP_IO4: D24.2 (K), RN1.1 (R1.1); also elsewhere on the board
/MCU/EXP_IO5: D28.1 (K), RN2.4 (R4.1); also elsewhere on the board
/MCU/EXP_IO6: D28.2 (K), RN2.3 (R3.1); also elsewhere on the board
/MCU/EXP_IO7: D32.1 (K), RN2.2 (R2.1); also elsewhere on the board
/MCU/EXP_IO8: D32.2 (K), RN2.1 (R1.1); also elsewhere on the board
/MCU/EXP_IO9: D21.1 (K), RN3.4 (R4.1); also elsewhere on the board
/MCU/EXP_IO10: D21.2 (K), RN3.3 (R3.1); also elsewhere on the board
/MCU/EXP_IO11: D25.1 (K), RN3.2 (R2.1); also elsewhere on the board
/MCU/EXP_IO12: D25.2 (K), RN3.1 (R1.1); also elsewhere on the board
/MCU/EXP_IO13: D29.1 (K), RN4.4 (R4.1); also elsewhere on the board
/MCU/EXP_IO14: D29.2 (K), RN4.3 (R3.1); also elsewhere on the board
/MCU/EXP_IO15: D33.1 (K), RN5.4 (R4.1); also elsewhere on the board
/MCU/EXP_IO16: D33.2 (K), RN5.3 (R3.1); also elsewhere on the board
/MCU/EXP_IO17: D22.1 (K), RN5.2 (R2.1); also elsewhere on the board
/MCU/EXP_IO18: D22.2 (K), RN5.1 (R1.1); also elsewhere on the board
/MCU/EXP_IO19: D26.1 (K), RN6.4 (R4.1); also elsewhere on the board
/MCU/EXP_IO20: D26.2 (K), RN6.3 (R3.1); also elsewhere on the board
/MCU/EXP_IO21: D30.1 (K), RN6.2 (R2.1); also elsewhere on the board
/MCU/EXP_IO22: D30.2 (K), RN6.1 (R1.1); also elsewhere on the board
/MCU/EXP_IO23: D34.1 (K), RN7.4 (R4.1); also elsewhere on the board
/MCU/EXP_IO24: D34.2 (K), RN7.3 (R3.1); also elsewhere on the board
/MCU/EXP_IO25: D23.1 (K), RN7.2 (R2.1); also elsewhere on the board
/MCU/EXP_IO26: D23.2 (K), RN7.1 (R1.1); also elsewhere on the board
/MCU/EXP_IO27: D27.1 (K), RN8.4 (R4.1); also elsewhere on the board
/MCU/EXP_IO28: D27.2 (K), RN8.3 (R3.1); also elsewhere on the board
/MCU/EXP_IO29: D31.1 (K), RN8.2 (R2.1); also elsewhere on the board
/MCU/EXP_IO30: D31.2 (K), RN8.1 (R1.1); also elsewhere on the board
GND: D20.3 (A), D21.3 (A), D22.3 (A), D23.3 (A), D24.3 (A), D25.3 (A), D26.3 (A), D27.3 (A), D28.3 (A), D29.3 (A), D30.3 (A), D31.3 (A), D32.3 (A), D33.3 (A), D34.3 (A), J24.15, J24.16, J24.27, J24.28, J24.39, J24.40; also elsewhere on the board
unnamed: J24.5, RN1.5 (R4.2)
unnamed: J24.6, RN1.6 (R3.2)
unnamed: J24.7, RN1.7 (R2.2)
unnamed: J24.8, RN1.8 (R1.2)
unnamed: J24.9, RN2.5 (R4.2)
unnamed: J24.10, RN2.6 (R3.2)
unnamed: J24.11, RN2.7 (R2.2)
unnamed: J24.12, RN2.8 (R1.2)
unnamed: J24.13, RN3.5 (R4.2)
unnamed: J24.14, RN3.6 (R3.2)
unnamed: J24.17, RN3.7 (R2.2)
unnamed: J24.18, RN3.8 (R1.2)
unnamed: J24.19, RN4.5 (R4.2)
unnamed: J24.20, RN4.6 (R3.2)
unnamed: J24.21, RN5.5 (R4.2)
unnamed: J24.22, RN5.6 (R3.2)
unnamed: J24.23, RN5.7 (R2.2)
unnamed: J24.24, RN5.8 (R1.2)
unnamed: J24.25, RN6.5 (R4.2)
unnamed: J24.26, RN6.6 (R3.2)
unnamed: J24.29, RN6.7 (R2.2)
unnamed: J24.30, RN6.8 (R1.2)
unnamed: J24.31, RN7.5 (R4.2)
unnamed: J24.32, RN7.6 (R3.2)
unnamed: J24.33, RN7.7 (R2.2)
unnamed: J24.34, RN7.8 (R1.2)
unnamed: J24.35, RN8.5 (R4.2)
unnamed: J24.36, RN8.6 (R3.2)
unnamed: J24.37, RN8.7 (R2.2)
unnamed: J24.38, RN8.8 (R1.2)

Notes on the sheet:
Expansion Header
Each signal pin protected with TVS diode and 150 ohm series resistor. Connector is IDC 40 pin, designed to have both cable or a board plugged into. PCB should include standoffs for larger expansion boards.

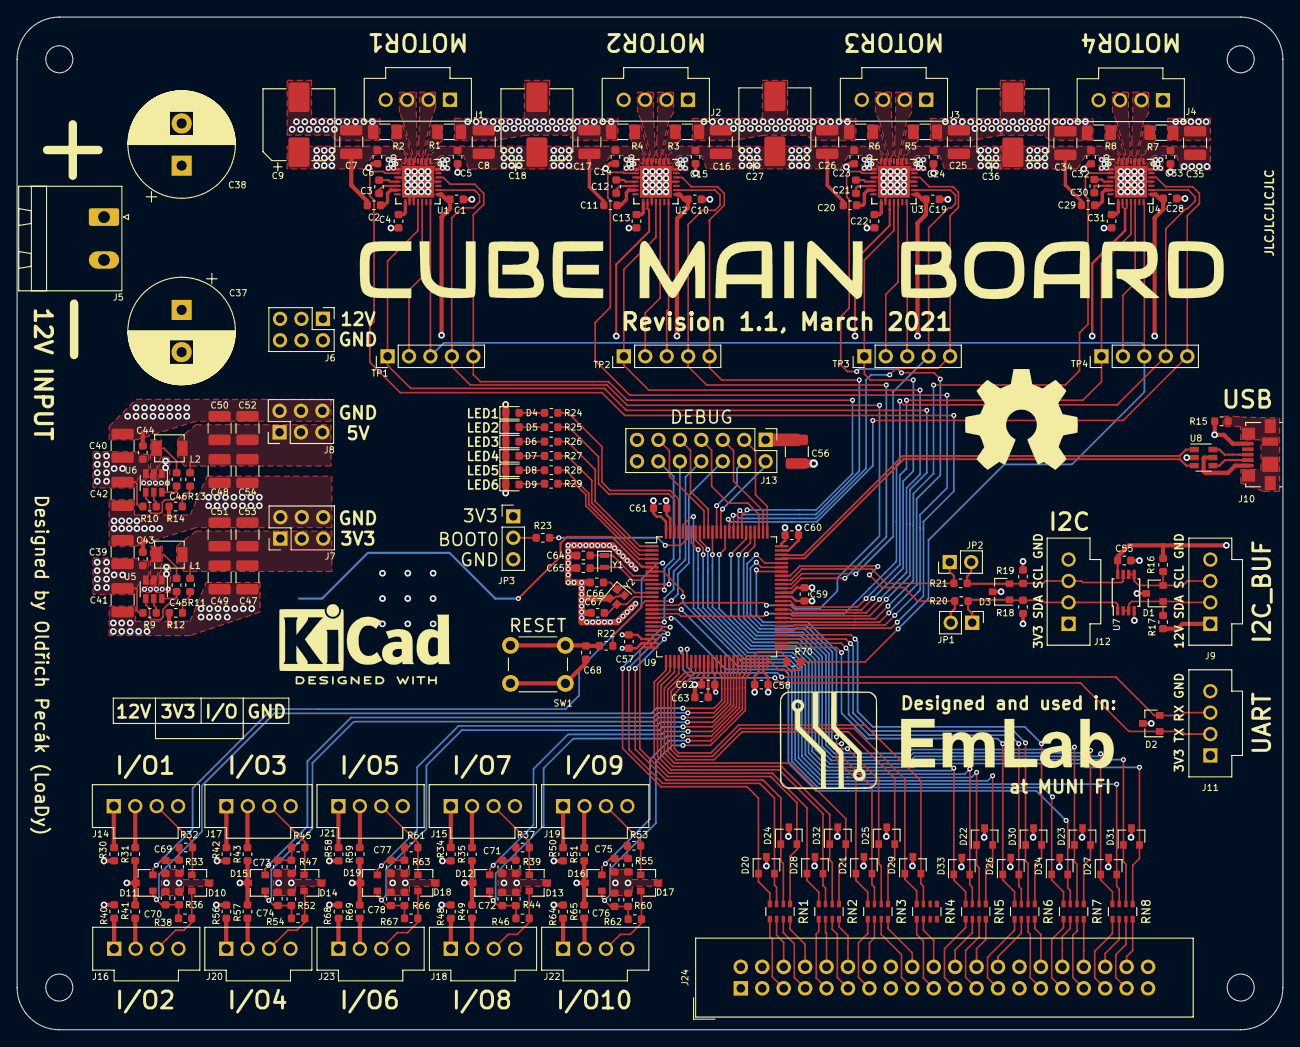
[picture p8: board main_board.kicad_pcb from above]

Board: 4 copper layers, 150.0 x 120.0 mm, 236 parts (1 on the bottom side), 220 nets.

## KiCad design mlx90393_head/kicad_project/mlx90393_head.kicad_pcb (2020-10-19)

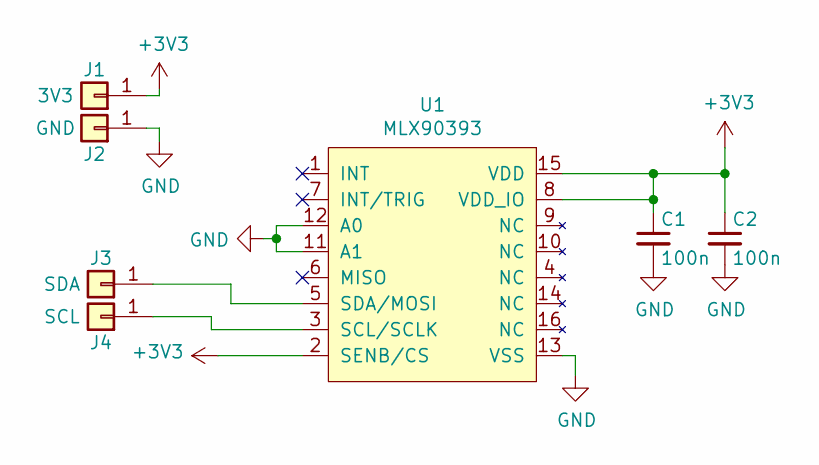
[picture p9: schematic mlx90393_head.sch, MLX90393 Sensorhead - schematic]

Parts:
C1, C2: 100n; C_0603_1608Metric
J1: 3V3; TestPoint_Pad_1.5x1.5mm
J2: GND; TestPoint_Pad_1.5x1.5mm
J3: SDA; TestPoint_Pad_1.5x1.5mm
J4: SCL; TestPoint_Pad_1.5x1.5mm
U1: MLX90393; QFN-16-1EP_3x3mm_P0.5mm_EP1.75x1.75mm

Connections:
+3V3: C1.1, C2.1, J1.1, U1.2 (SENB/CS), U1.8 (VDD_IO), U1.15 (VDD)
GND: C1.2, C2.2, J2.1, U1.11 (A1), U1.12 (A0), U1.13 (VSS), U1.17 (PAD)
unnamed: J3.1, U1.5 (SDA/MOSI)
unnamed: J4.1, U1.3 (SCL/SCLK)

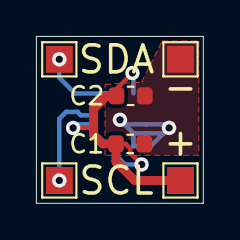
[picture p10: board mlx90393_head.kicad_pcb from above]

Board: 2 copper layers, 9.3 x 9.3 mm, 7 parts (1 on the bottom side), 4 nets.

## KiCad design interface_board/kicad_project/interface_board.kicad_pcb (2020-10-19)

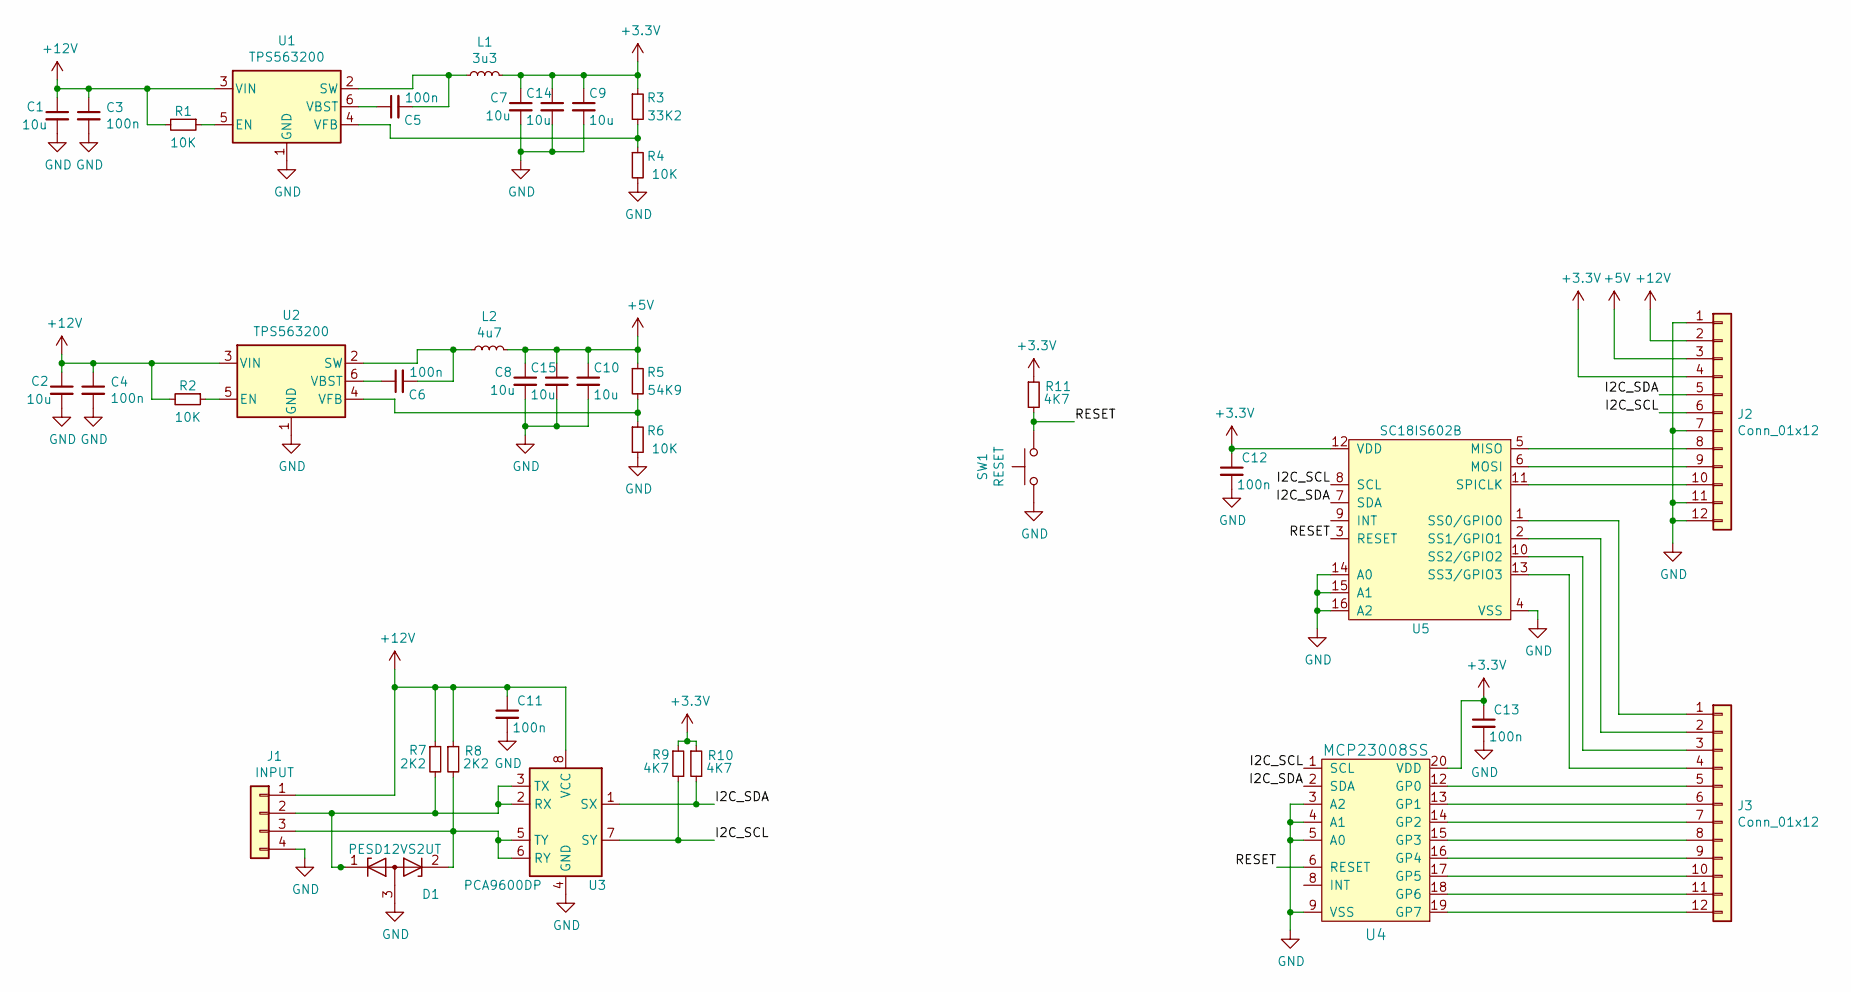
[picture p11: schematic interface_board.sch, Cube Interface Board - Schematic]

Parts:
C1, C2, C7, C8, C9, C10, C14, C15: 10u; C_1210_3225Metric
C3, C4, C5, C6, C11, C12, C13: 100n; C_0603_1608Metric
D1: PESD12VS2UT; SOT-23
J1: INPUT; Molex_70543-0003
J2, J3: Conn_01x12; PinHeader_1x12_P2.54mm_Vertical
L1: 3u3; BOURNS_SRP3020TA
L2: 4u7; BOURNS_SRP3020TA
R1, R2, R4, R6: 10K; R_0603_1608Metric
R3: 33K2; R_0603_1608Metric
R5: 54K9; R_0603_1608Metric
R7, R8: 2K2; R_0603_1608Metric
R9, R10, R11: 4K7; R_0603_1608Metric
SW1: RESET; SolderJumper-2_P1.3mm_Open_Pad1.0x1.5mm
U1, U2: TPS563200; SOT-23-6
U3: PCA9600DP; TSSOP-8_3x3mm_P0.65mm
U4: MCP23008SS; SSOP-20_5.3x7.2mm_P0.65mm
U5: SC18IS602B; TSSOP-16_4.4x5mm_P0.65mm

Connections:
+3V3: C7.1, C9.1, C12.1, C13.1, C14.1, J2.4, L1.2, R3.1, R9.1, R10.1, R11.1, U4.20 (VDD), U5.12 (VDD)
+5V: C8.1, C10.1, C15.1, J2.3, L2.2, R5.1
+12V: C1.1, C2.1, C3.1, C4.1, C11.1, J1.1, J2.2, R1.2, R2.2, R7.1, R8.1, U1.3 (VIN), U2.3 (VIN), U3.8 (VCC)
/I2C_SCL: J2.6, R9.2, U3.7 (SY), U4.1 (SCL), U5.8 (SCL)
/I2C_SDA: J2.5, R10.2, U3.1 (SX), U4.2 (SDA), U5.7 (SDA)
/RESET: R11.2, SW1.2, U4.6 (RESET), U5.3 (RESET)
GND: C1.2, C2.2, C3.2, C4.2, C7.2, C8.2, C9.2, C10.2, C11.2, C12.2, C13.2, C14.2, C15.2, D1.3 (A), J1.4, J2.1, J2.7, J2.11, J2.12, R4.2, R6.2, SW1.1, U1.1 (GND), U2.1 (GND), U3.4 (GND), U4.3 (A2), U4.4 (A1), U4.5 (A0), U4.9 (VSS), U5.4 (VSS), U5.14 (A0), U5.15 (A1), U5.16 (A2)
unnamed: C5.1, U1.6 (VBST)
unnamed: C5.2, L1.1, U1.2 (SW)
unnamed: C6.1, U2.6 (VBST)
unnamed: C6.2, L2.1, U2.2 (SW)
unnamed: D1.1 (K), J1.2, R7.2, U3.2 (RX), U3.3 (TX)
unnamed: D1.2 (K), J1.3, R8.2, U3.5 (TY), U3.6 (RY)
unnamed: J2.8, U5.5 (MISO)
unnamed: J2.9, U5.6 (MOSI)
unnamed: J2.10, U5.11 (SPICLK)
unnamed: J3.1, U5.1 (SS0/GPIO0)
unnamed: J3.2, U5.2 (SS1/GPIO1)
unnamed: J3.3, U5.10 (SS2/GPIO2)
unnamed: J3.4, U5.13 (SS3/GPIO3)
unnamed: J3.5, U4.12 (GP0)
unnamed: J3.6, U4.13 (GP1)
unnamed: J3.7, U4.14 (GP2)
unnamed: J3.8, U4.15 (GP3)
unnamed: J3.9, U4.16 (GP4)
unnamed: J3.10, U4.17 (GP5)
unnamed: J3.11, U4.18 (GP6)
unnamed: J3.12, U4.19 (GP7)
unnamed: R1.1, U1.5 (EN)
unnamed: R2.1, U2.5 (EN)
unnamed: R3.2, R4.1, U1.4 (VFB)
unnamed: R5.2, R6.1, U2.4 (VFB)

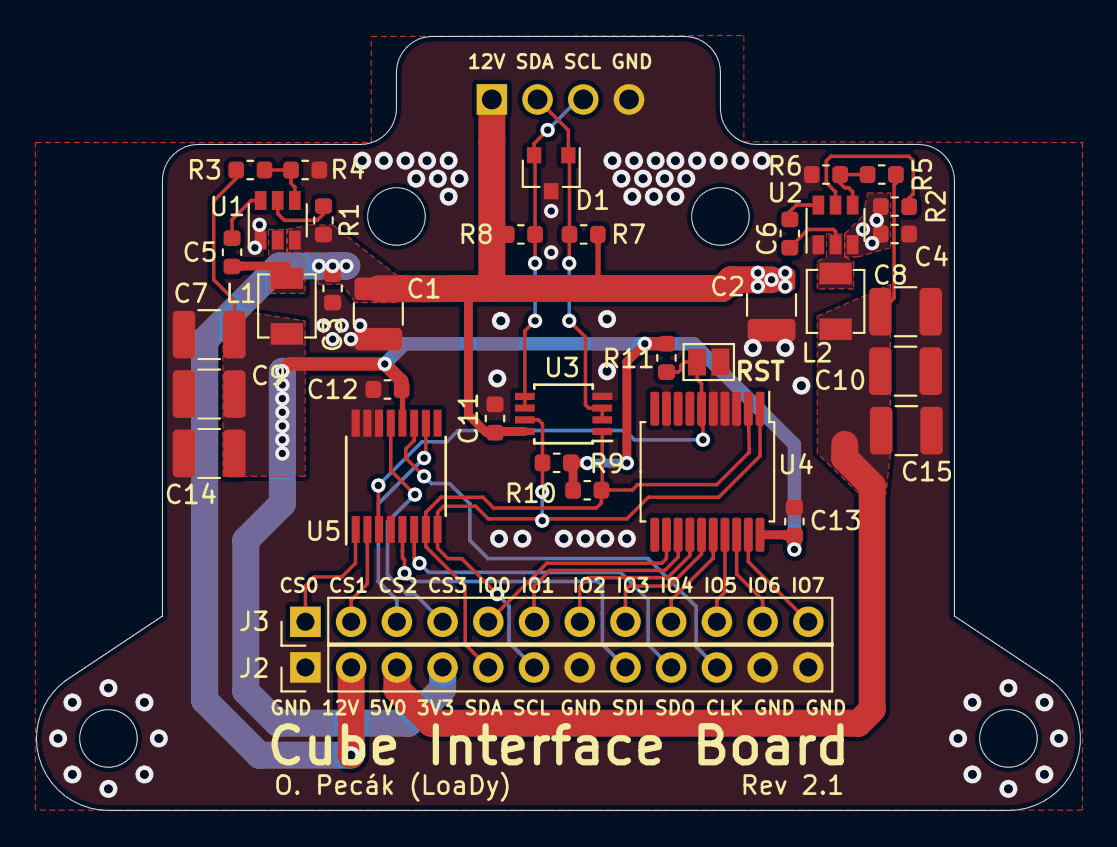
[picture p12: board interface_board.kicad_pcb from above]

Board: 2 copper layers, 58.0 x 43.0 mm, 38 parts (1 on the bottom side), 32 nets.

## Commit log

2020-08-31 start repo, add interface board
    [interface_board.kicad_pcb, interface_board.sch]
2020-08-31 add start of main board
    [main_board.kicad_pcb, main_board.sch, stepper_driver.sch]
2020-08-31 add MLX90393 sensor head
    [sensorhead.kicad_pcb, sensorhead.sch]
2020-08-31 add power to main board
    [main_board.sch, power.sch, stepper_driver.sch]
2020-09-01 add readmes, add MCU to main board, update footprints on interface board
    [MCU.sch, interface_board.kicad_pcb, main_board.sch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]
2020-09-02 add input/output schematic, add documentation
    [MCU.sch, input_output.sch, main_board.sch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]
2020-09-08 Fix I/O protection
    [input_output.sch, main_board.sch, stepper_driver.sch]
2020-09-08 rename sheets
    [limit_sw.sch, main_board.sch]
2020-09-08 remove old file
    [input_output.sch]
2020-09-08 add external IO
    [MCU.sch, limit_sw.sch, main_board.sch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]
2020-09-08 actually add external IO
    [external_io.sch]
2020-09-10 add input protection to interface board
    [interface_board.kicad_pcb, interface_board.sch]
2020-09-15 interface board add new connector and edit layout
    [interface_board.kicad_pcb]
2020-09-22 progress on MCU pinout
    [MCU.sch, external_io.sch, limit_sw.sch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]
2020-09-22 more progress on MCU pinout
    [MCU.sch]
2020-09-22 fix bus connection
    [MCU.sch, limit_sw.sch, main_board.sch]
2020-09-23 MCU pinout done
    [MCU.sch, expansion.sch, external_io.sch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]
2020-09-23 schematic rev1 finished
    [MCU.sch, expansion.sch, external_io.sch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]
2020-09-24 main board: layout start, steppers done
    [external_io.sch, limit_sw.sch, main_board.kicad_pcb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]
2020-09-24 edits to stepper layout
    [main_board.kicad_pcb]
2020-09-25 regulators layout done
    [main_board.kicad_pcb]
2020-09-26 limit switch layout
    [main_board.kicad_pcb]
2020-09-26 expansion connector - rev 1.1 schematic, finished layout
    [expansion.sch, main_board.kicad_pcb, stepper_driver.sch]
2020-09-27 external IO layout WIP, small chances to external IO schematic
    [external_io.sch, main_board.kicad_pcb]
2020-09-28 routing half finished
    [MCU.sch, external_io.sch, main_board.kicad_pcb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]
2020-09-28 routing finished
    [main_board.kicad_pcb]
2020-09-28 add graphics
    [main_board.kicad_pcb]
2020-10-10 Main board sch: add backup battery, update license
    [MCU.sch, expansion.sch, external_io.sch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]
2020-10-18 change connector for interface board, edit silkscreen layers for interface and main boards
    [interface_board.kicad_pcb, interface_board.sch, main_board.kicad_pcb]
2020-10-19 change oshw logo pos on mainboard
    [main_board.kicad_pcb]
2020-10-19 add interface board silkscreen, modify main board silkscreen
    [interface_board.kicad_pcb, main_board.kicad_pcb]
2020-10-19 edit READMEs, add LICENCE.txt
    [sensorhead.kicad_pcb, sensorhead.sch]
2020-10-19 update TMC2209 footprints on main board
    [main_board.kicad_pcb]
2020-10-23 change folder names, add makefile
    [MCU.sch, expansion.sch, external_io.sch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]
2021-03-13 change resistor network package
    [expansion.sch, main_board.kicad_pcb]

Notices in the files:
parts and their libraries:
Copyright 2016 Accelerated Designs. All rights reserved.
